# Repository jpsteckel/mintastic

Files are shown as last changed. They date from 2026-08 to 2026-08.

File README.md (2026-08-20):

# Minstastic: Altoids Tin Meshtastic Node
**Mintastic is a low-cost LoRa meshtastic node built as an**
[**Altoids tin gadget**](https://www.instructables.com/10-Projects-for-Altoids-Tins "Other examples")**.**

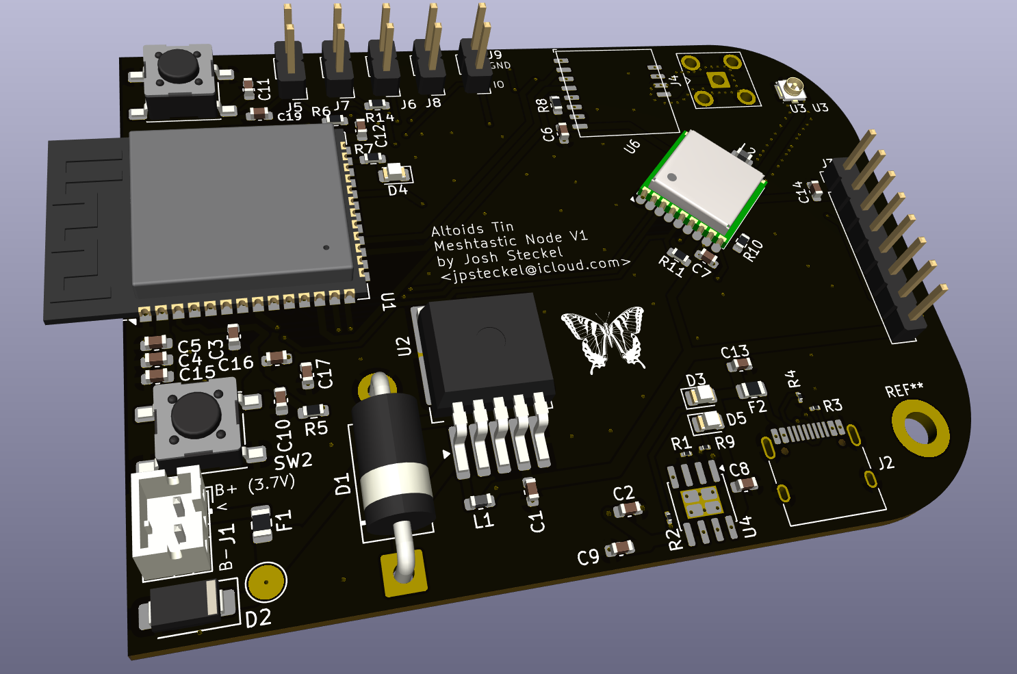
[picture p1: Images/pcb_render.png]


## Abstract
**Note: this project is still a work in progress. I plan on updating and finishing this project by early September.**

This project presents the design and implementation of a compact, low-cost Meshtastic mesh networking node packaged in an everyday Altoids tin enclosure. Motivated by the need for a fully standalone node on a campus mesh network, the device integrates a custom PCB featuring an ESP32 microcontroller, SX1262 LoRa transceiver operating at 915 MHz, GPS module, navigation buttons, and LCD display for a custom user interface. Power is supplied by a 3.7 V 1500 mAh LiPo battery with on-board charging circuitry, while an external whip antenna supports long-range communication. <!-- The completed node achieves approximately 6 miles of unobstructed range (mountain-to-mountain) with an average current draw of 0.150 mA. --> The design demonstrates practical RF system integration, efficient power management, and mechanical packaging constraints, resulting in a portable, inexpensive, and self-contained mesh node suitable for campus and outdoor applications.

## 1. Requirements
|  | Requirement |
|---|---|
| Power | 3.7V 1500mAh LiPo battery with JST connector, approx 1x2 inches. |
| Size | <58mm width. I've gone with 55x75mm to leave room for battery. |
| Bluetooth | Connects via bluetooth to mobile phone with Meshtastic app |
| GPS | Built-in GPS capability for off-grid use |
| Cost | As cheap as possible for me to prototype, <$50/unit "build it yourself" cost |
| Personal Learning Goals | Learn RF and digital PCB design, and build first highly documented project. |

**Preferred Qualities:**
|  | Goal |
|---|---|
| Standalone | Usable without external bluetooth device through built-in user interface |
| Range | ~ 6 mile unobscured |
| Battery Life | >10 hours / <150mA average consumption |

## 2. Design
### Power
The first design concern is being able to both power the board using the LiPo battery, and recharge it. Luckily, most all ESP32, LoRa, and GPS chips support 3.3V VCC, so I only need one regulator chip. I've decided on the **LM2575S-3.3** switching regulator for its efficiency and availability.

For charging and off-board power, I've chosen the **TP4056**, a common charging chip which is powered by 5V via USB-C and outputs 3.7V. This will connect to VBAT which connects to the battery as well as VIN on the regulator.

The circuits surrounding these respective components have been copied mostly from their datasheets.

### MCU
Mintastic will use an ESP32 due to their native bluetooth features. Most could handle this job, I have chosen the **ESP32 S3 N16R8**. Although it costs slightly more than other modules, its large flash memory gives me a lot of room to add features in the future without needing to upgrade hardware.

**Full MCU Pinout**
| ESP32 Pin | Connection | Pulled high/low/NA |
| - | - | - |
| EN | Reset Button | High |
| IO0 | Boot Button | High |
| IO1 | Battery Divider | |
| IO2 | User Button | High |
| IO3 | User Button | High |
| IO4 | GPS Reset | High |
| IO5 | GPS On/Off | High |
| IO6 | User Button | High |
| IO7 | User Button | High |
| IO8 | LoRa SCK | |
| IO9 | LoRa MISO | |
| IO10 | LoRa MOSI | |
| IO11 | LCD Reset | |
| IO12 | LCD SDA | |
| IO13 | LCD SCL | |
| IO14 | LCD CS | |
| IO15 | LCD DC | |
| IO16 | User Button | High |
| IO17 | GPS Tx | |
| IO18 | GPS Rx | |
| USB+ | USB D+ | |
| USB- | USB D- | |
| IO38 | LoRa RF Switch | |
| IO39 | LoRa DIO1 | |
| IO40 | LoRa Busy | |
| IO41 | LoRa NSS | |
| IO42 | LoRa Reset | |
| IO46 | | unconnected/low |
| IO48 | Red LED | |

Note: The periferal connections were decided (mostly) arbitrarily or based on firmware defaults.

All other pins are unconnected.

### Periferals
#### I. LoRa Module
The Semtech SX1262 is the LoRa IC used almost universally for Mesh nodes. For simplicity, I will use the [**Wio-SX1262**](https://wiki.seeedstudio.com/wio_sx1262/) module by Seeed Studio. This compact module features an onboard filter, switch, and IPEX connector, making it ideal for this. (I will be using a separate SMA connector rather than the IPEX for LoRa.)

#### II. GPS Module
I do not want to be reliant on a mobile phone's internet connection for location information, so I plan to use an on-board GPS chip. I've selected the cheap chinese [**ATGM336H**](https://www.alldatasheet.com/html-pdf/2250270/ZHONGKE/ATGM336H/2443/7/ATGM336H.html) module to support GPS for this module.

#### III. 2.4 Inch TFT LCD Display
I've selected a generic ST7789 display for this with a built-in controller. I will simply connect it through a 1x8 pin socket.

### PCB
To fit design constraints, I've set the width of the PCB to be just under the inner lip diameter of the Altoids tin, 55mm, and its height to be ~ 40 mm less than the length of the tin, 75mm, to leave room for the battery. I've also rounded 2 of the board's edges to match the curvature of the tin.

To lower costs, I've decided to use a 2-layer board over a simpler 4-layer design. For this reason, I will need to separate UHF from digital signals so that they can have a solid ground plane beneath each trace.

The dielectric between the layers is far too thick for impedance controlled microstrip traces, so I will use the GCPW (Grounded Coplanar Waveguide) technique.

**Impedance control**

To calculate impedance values, I am using an [online calculator](https://impedancecalculator.com/). 
UHF signal traces will need to be impedance controlled to 50 Ohms. Using GCPW, this requires a 1 mm trace and 0.2 mm gap. This gets us down to 55.7 Ohms, resulting in 0.556 dB/inch loss at 900 MHz. Close enough for this ~0.1 inch line.

I've determined the microstrip traces to have a reasonable impedance for digital signals.

### UI Design

## 3. Manufacturing
Prototype fabricated through JLCPCB. All components were ordered through AliExpress. I assembled the PCB myself using SMT tools at UD.

**Prototype cost breakdown:**
| Item | Cost ($) | Note |
| ---- | ---- | ---- |
| PCB | 4.95 | 24.75/5, includes shipping |
| [Capacitors](https://www.aliexpress.com/item/3256810330121955.html?spm=a2g0o.order_list.order_list_main.10.21ef1802iwNV2p) | 0.20 | 3.19/320 * 20 |
| [Resistors](https://www.aliexpress.com/item/3256810577510361.html?spm=a2g0o.order_list.order_list_main.32.21ef1802iwNV2p) | 0.07 | 2.37/660 * 19 |
| [Inductors](https://www.aliexpress.com/item/3256808828460642.html?spm=a2g0o.order_list.order_list_main.78.21ef1802iwNV2p) | 0.03 | 4.35/300 * 0.029 |
| [LEDs](https://www.aliexpress.com/item/2251800651687366.html?spm=a2g0o.order_list.order_list_main.114.21ef1802iwNV2p) | 0.05 | 1.51/100 * 3 |
| [Resettable Fuses](https://www.aliexpress.com/item/3256805049615392.html?spm=a2g0o.order_list.order_list_main.44.21ef1802iwNV2p) | 0.33 | 3.32/20 * 2 |
| [SS14 Diode](https://www.aliexpress.com/item/3256806391314857.html?spm=a2g0o.order_list.order_list_main.26.21ef1802iwNV2p) | 0.03 | 1.47/50 |
| [IN5819 Diode](https://www.aliexpress.com/item/3256801365779334.html?spm=a2g0o.order_list.order_list_main.425.21ef1802iwNV2p) | 0.02 | 0.91/50
| [USB-C Connector](https://www.aliexpress.com/item/3256804454151365.html?spm=a2g0o.order_list.order_list_main.435.21ef1802iwNV2p) | 0.22 | 2.19/10 |
| [Battery JST connector](https://www.aliexpress.com/item/3256807568732637.html?spm=a2g0o.order_list.order_list_main.102.21ef1802iwNV2p) | 0.09 | 1.77/20 |
| [LiPo Battery](https://www.aliexpress.com/item/3256808031709894.html?spm=a2g0o.order_list.order_list_main.84.21ef1802iwNV2p) | 6.73 | |
| [TP4056](https://www.aliexpress.com/item/2251832528051428.html?spm=a2g0o.order_list.order_list_main.96.21ef1802iwNV2p) | 0.10 | 0.94/10 |
| [LM2575S-3.3](https://www.aliexpress.com/item/3256806770889152.html?spm=a2g0o.order_list.order_list_main.50.21ef1802iwNV2p) | 0.28 | 5.54/20 |
| [ESP32-S3-N16R8](https://www.aliexpress.com/item/3256806005505510.html?spm=a2g0o.order_list.order_list_main.90.21ef1802iwNV2p) | 4.79 | |
| [WIO-SX1262](https://www.aliexpress.com/item/3256808235584580.html?spm=a2g0o.order_list.order_list_main.451.21ef1802iwNV2p) | 4.97 | |
| [ATGM336H](https://www.aliexpress.com/item/3256804828510067.html?spm=a2g0o.order_list.order_list_main.66.21ef1802iwNV2p) | 3.04 | |
| [IPEX connector](https://www.aliexpress.com/item/3256801185019750.html?spm=a2g0o.order_list.order_list_main.108.21ef1802iwNV2p) | 0.15 | 1.50/10 |
| [SMA connector](https://www.aliexpress.com/item/3256807238600626.html?spm=a2g0o.order_list.order_list_main.475.21ef1802iwNV2p) | 0.77 | 3.86/5  |
| [SMA Cable](https://www.aliexpress.com/item/3256803838912502.html?spm=a2g0o.order_list.order_list_main.38.21ef1802iwNV2p) | 2.34 | |
| [2.4in TFT LCD Display](https://www.aliexpress.com/item/3256811879116899.html?spm=a2g0o.order_list.order_list_main.125.21ef1802iwNV2p) | 5.57 | |
| [8-pin socket](https://www.aliexpress.com/item/3256804056304729.html?spm=a2g0o.order_list.order_list_main.72.21ef1802iwNV2p) | 0.19 | 1.94/10 |
| [2-pin headers](https://www.aliexpress.com/item/3256807300285852.html?spm=a2g0o.order_list.order_list_main.140.21ef1802iwNV2p) | 0.05 | 1.63/180 * 5 |
| [Push Buttons](https://www.aliexpress.com/item/3256808033339761.html?spm=a2g0o.order_list.order_list_main.510.21ef1802iwNV2p) | 0.05 | 0.99/100 * 5 |
| [UHF Whip Antenna](https://www.aliexpress.us/item/3256804421300249.html) | 4.60 | |
| [GPS Antenna](https://www.aliexpress.com/item/2251832500323977.html?spm=a2g0o.order_list.order_list_main.20.21ef1802iwNV2p) | 1.59 | |
| Altoids tin | 0.00 | Everyone has one somewhere
| Total | 41.20 | |

Note on above calculations: This is a rough estimate of how much each unit costs at a small scale to self-assemble. Many components, such as resistors, I had to buy in kits. In these cases, I took the cost of the kit, divided it by the total number of pieces included, and multiplied by the number of that component per unit. $40 is about the lowest you will find a mesh node for on Amazon, so this is a reasonable cost. It goes without saying that I would use PCBA for production at scale, but for this project it would have cost ~$193.

## 4. Measurement Setup
...

## 5. Results
| Spec | Target | Simulated | Measured |
| ---- | --- | --- | --- |
|
[Plots]

## 6. Discussion & Lessons Learned
...

## 7. Conclusion
...

## References
I was inspired by Martin Held's [Altoids tin CW radio](https://www.youtube.com/watch?v=zBLEqTVUgEY&list=WL&index=7&pp=iAQBsAgC) project.

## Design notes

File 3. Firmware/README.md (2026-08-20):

# ESP32-S3-N18R8 Metastatic Node — boilerplate

FreeRTOS-based skeleton for a mesh node built around the ESP32-S3 (8MB PSRAM)
and an ST7789V TFT LCD. Right now it only brings up the display so you can
design the UI; other subsystems are scaffolded as stub tasks so they drop
in later without restructuring anything.

## Structure

```
platformio.ini            Build config, board, libs
include/
  config.h                Pin mapping + task stack/priority/core sizing
  shared_state.h           Mutex-guarded NodeState shared across tasks
src/
  main.cpp                 setup()/loop(): creates shared state, starts tasks
  shared_state.cpp          Global SharedState instance
  ui/
    ui.h / ui.cpp           <-- DESIGN THE DISPLAY LOOK HERE
  tasks/
    display_task.h/.cpp     Owns the SPI panel + render loop, calls ui::render()
    system_task.h/.cpp      Heartbeat: updates uptime, prints serial status
    gps_task.h/.cpp          Stub — not started yet
    input_task.h/.cpp       Stub — not started yet
    mesh_task.h/.cpp        Stub — not started yet (Meshtastic goes here)
```

## Why it's laid out this way

- **One task per subsystem**, each pinned to a core and given a priority in
  `config.h`. Display/system run now; GPS/input/mesh are already sized and
  prioritized but not started (commented out in `main.cpp`).
- **`SharedState`** is the only thing tasks share. It's a mutex-protected
  struct (`NodeState`) with `read()` and `update()` helpers — no task talks
  to another task directly, which keeps things sane once GPS, input, and
  Meshtastic are all producing/consuming data at the same time.
- **`ui.cpp` is intentionally decoupled from `display_task.cpp`.** The task
  owns the SPI bus and the timing loop; `ui::render()` just gets a `tft`
  reference and a read-only `NodeState` snapshot every frame. Redesign the
  look by editing `ui.cpp` only — you shouldn't need to touch the task code.

## Before you build

1. **Wiring** — `include/config.h` has placeholder SPI pins for the ST7789V
   (`TFT_SCLK/MOSI/CS/DC/RST/BL`). Update them to match your actual wiring.
2. **Panel size** — defaults to 240x240; change `TFT_WIDTH`/`TFT_HEIGHT` if
   your module is 240x320 (and adjust `TFT_ROTATION` as needed).
3. **Board** — `platformio.ini` targets `esp32-s3-devkitc-1` with QIO octal
   PSRAM (`qio_opi`) and a 16MB flash partition table. Adjust
   `board_upload.flash_size` / `board_build.partitions` if your module's
   flash size differs from what "N18" maps to on your specific board.

## Build / flash

```
pio run -t upload
pio device monitor
```

You should get a black screen with a green node-name header, a live
uptime/status readout, and a blinking dot in the bottom-right corner
confirming the render loop is alive — that's your canvas to redesign.

## Next steps (already scaffolded, not wired in)

- **GPS**: implement `gps_task.cpp` (e.g. with TinyGPS++ over `Serial1` on
  `GPS_RX_PIN`/`GPS_TX_PIN`), then uncomment `gpsTaskStart()` in `main.cpp`.
- **Input**: implement `input_task.cpp` against `BTN_*_PIN` (or swap in an
  encoder library), then uncomment `inputTaskStart()`.
- **Meshtastic**: implement `mesh_task.cpp` around the Meshtastic firmware
  components/library of choice, then uncomment `meshTaskStart()`. It's
  already given the highest task priority in `config.h` since radio timing
  tends to be the most latency-sensitive thing on the node.

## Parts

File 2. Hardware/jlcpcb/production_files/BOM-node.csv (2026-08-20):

Comment | Designator | Footprint | LCSC | Quantity
100k | R18 | R_0805_2012Metric | C149504 | 1
100nF | C10,C11,C12,C15,C16,C17,C18,C19,C20,C21,C22,C23,C3,C5 | C_0603_1608Metric | C14663 | 14
10k | R10,R11,R12,R14,R15,R16,R17,R5,R6,R8 | R_0603_1608Metric | C29718 | 10
10uF | C13,C14,C4,C6,C7,C8,C9 | C_0603_1608Metric | C19702 | 7
10uH | L2 | L_0603_1608Metric | C1035 | 1
1k | R2,R9 | R_0201_0603Metric | C21190 | 2
2.0k | R1 | R_0201_0603Metric | C22975 | 1
220k | R19 | R_0805_2012Metric | C17556 | 1
22uF | C1,C2 | C_0603_1608Metric | C59461 | 2
330 | R13,R7 | R_0603_1608Metric | C23138 | 2
5.1k | R3,R4 | R_0201_0603Metric | C23186 | 2
68uH | L1 | L_0603_1608Metric | C13415 | 1
ATGM336H-6N-74 | U6 | C5804601_COMM-SMD_18P-L10_1-W9_7-P1_1-TL_L76-LB | C5804601 | 1
Green | D5 | LED_0805_2012Metric | C2297 | 1
IPEX-1 | U3 | C2987682_IPEX-SMD_4P-L2_6-W2_6-LS3_0 | C2987682 | 1
Polyfuse 1A | F1,F2 | Fuse_0805_2012Metric | C269104 | 2
RED | D4 | LED_0805_2012Metric | C84256 | 1
SS14 | D2 | D_SMA | C7420316 | 1
TP4056-42-ESOP8 | U4 | SOIC-8-1EP_3.9x4.9mm_P1.27mm_EP2.41x3.3mm_ThermalVias | C16581 | 1
Yellow | D3 | LED_0805_2012Metric | C2296 | 1
USB_C_Receptacle | J2 | USB_C_Receptacle_HRO_TYPE-C-31-M-12 |  | 1
Conn_01x08_Socket | J3 | PinHeader_1x08_P2.54mm_Vertical |  | 1
Wio-SX1262 | U5 | MODULE12P-1.27-11X11.6MM |  | 1
LM2595S-3.3 | U2 | TO-263-5_TabPin3 |  | 1
ESP32-S3-WROOM-1 | U1 | ESP32-S3-WROOM-1 |  | 1
TestPoint | TP1 | TestPoint_Pad_D2.5mm |  | 1
SW_Push | SW4 | SW_SPST_PTS645Sx43SMTR92 |  | 1
SW_Push | SW2 | SW_SPST_PTS645Sx43SMTR92 |  | 1
SMA 915MHz | J4 | SMA_BAT_Wireless_BWSMA-KWE-Z001 |  | 1
Conn_01x02 | J1 | JST_PH_B2B-PH-K_1x02_P2.00mm_Vertical |  | 1
1N5822 | D1 | D_DO-201AD_P15.24mm_Horizontal |  | 1
Conn_01x02_Pin | J9 | PinHeader_1x02_P2.54mm_Vertical |  | 1
Conn_01x02_Pin | J8 | PinHeader_1x02_P2.54mm_Vertical |  | 1
Conn_01x02_Pin | J7 | PinHeader_1x02_P2.54mm_Vertical |  | 1
Conn_01x02_Pin | J6 | PinHeader_1x02_P2.54mm_Vertical |  | 1
Conn_01x02_Pin | J5 | PinHeader_1x02_P2.54mm_Vertical |  | 1

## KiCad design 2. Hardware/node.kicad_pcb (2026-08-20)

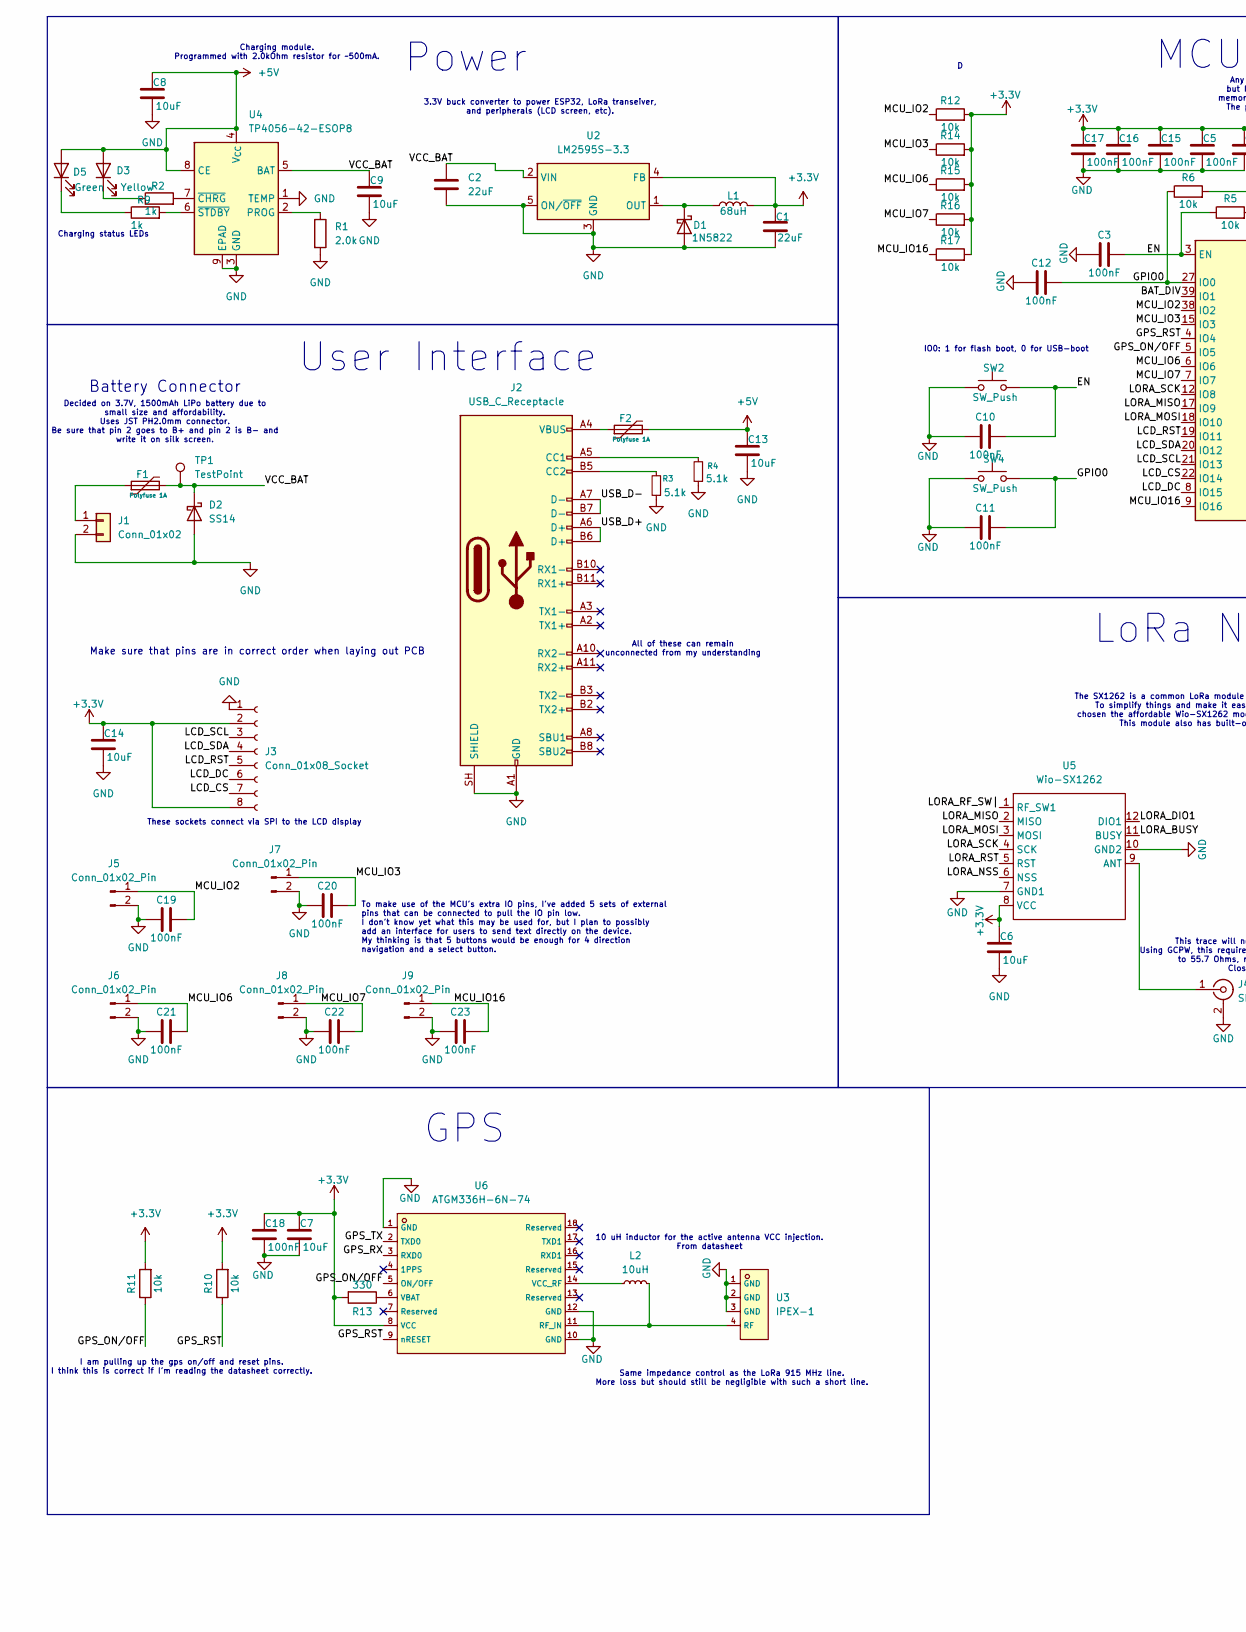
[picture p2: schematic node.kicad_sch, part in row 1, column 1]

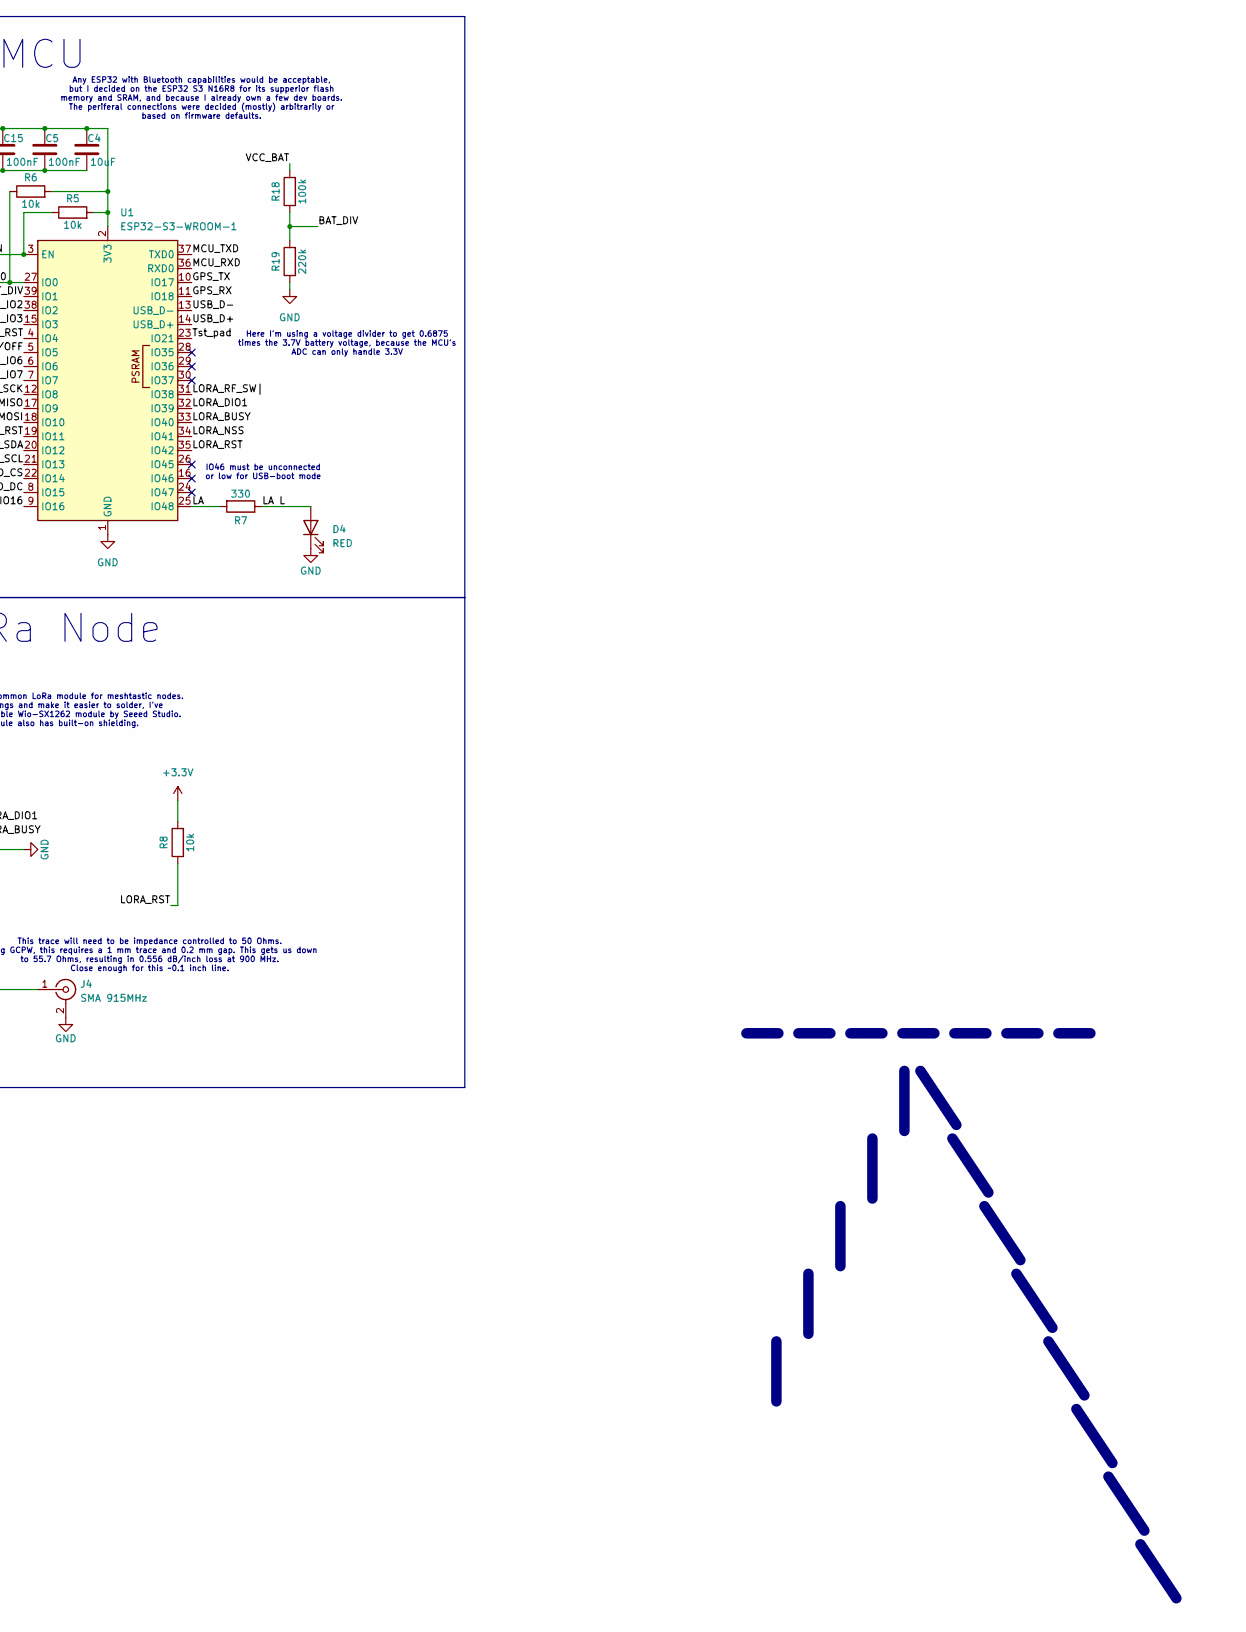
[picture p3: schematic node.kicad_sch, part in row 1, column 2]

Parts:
C1, C2: 22uF; C_0603_1608Metric
C3, C5, C10, C11, C12, C15, C16, C17, C18, C19, C20, C21, C22, C23: 100nF; C_0603_1608Metric
C4, C6, C7, C8, C9, C13, C14: 10uF; C_0603_1608Metric
D1: 1N5822; D_DO-201AD_P15.24mm_Horizontal
D2: SS14; D_SMA
D3: Yellow; LED_0805_2012Metric
D4: RED; LED_0805_2012Metric
D5: Green; LED_0805_2012Metric
F1, F2: Polyfuse 1A; Fuse_0805_2012Metric
J1: Conn_01x02; JST_PH_B2B-PH-K_1x02_P2.00mm_Vertical
J2: USB_C_Receptacle; USB_C_Receptacle_HRO_TYPE-C-31-M-12
J3: Conn_01x08_Socket; PinHeader_1x08_P2.54mm_Vertical
J4: SMA 915MHz; SMA_BAT_Wireless_BWSMA-KWE-Z001
J5, J6, J7, J8, J9: Conn_01x02_Pin; PinHeader_1x02_P2.54mm_Vertical
L1: 68uH; L_0603_1608Metric
L2: 10uH; L_0603_1608Metric
R1: 2.0k; R_0201_0603Metric
R2, R9: 1k; R_0201_0603Metric
R3, R4: 5.1k; R_0201_0603Metric
R5, R6, R8, R10, R11, R12, R14, R15, R16, R17: 10k; R_0603_1608Metric
R7, R13: 330; R_0603_1608Metric
R18: 100k; R_0805_2012Metric
R19: 220k; R_0805_2012Metric
SW2, SW4: SW_Push; SW_SPST_PTS645Sx43SMTR92
TP1: TestPoint; TestPoint_Pad_D2.5mm
U1: ESP32-S3-WROOM-1
U2: LM2595S-3.3; TO-263-5_TabPin3
U3: IPEX-1; C2987682_IPEX-SMD_4P-L2_6-W2_6-LS3_0; LCSC C2987682
U4: TP4056-42-ESOP8; SOIC-8-1EP_3.9x4.9mm_P1.27mm_EP2.41x3.3mm_ThermalVias
U5: Wio-SX1262; MODULE12P-1.27-11X11.6MM; MPN Wio-SX1262
U6: ATGM336H-6N-74; C5804601_COMM-SMD_18P-L10_1-W9_7-P1_1-TL_L76-LB; LCSC C5804601

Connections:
+3.3V: C1.1, C4.1, C5.1, C6.1, C7.1, C14.1, C15.1, C16.1, C17.1, C18.1, J3.2, J3.8, L1.2, R5.2, R6.2, R8.2, R10.2, R11.2, R12.2, R13.2, R14.2, R15.2, R16.2, R17.2, U1.2 (3V3), U2.4 (FB), U5.8 (VCC), U6.8 (VCC)
+5V: C8.1, C13.1, D3.2 (A), D5.2 (A), F2.2, U4.4 (V_{CC}), U4.8 (CE)
/BAT_DIV: R18.1, R19.2, U1.39 (IO1)
/EN: C3.2, C10.2, R5.1, SW2.2, U1.3 (EN)
/GPIO0: C11.2, C12.2, R6.1, SW4.2, U1.27 (IO0)
/GPS_ON/OFF: R11.1, U1.5 (IO5), U6.5 (ON/OFF)
/GPS_RST: R10.1, U1.4 (IO4), U6.9 (nRESET)
/GPS_RX: U1.11 (IO18), U6.3 (RXD0)
/GPS_TX: U1.10 (IO17), U6.2 (TXD0)
/LA: R7.2, U1.25 (IO48)
/LA L: D4.2 (A), R7.1
/LCD_CS: J3.7, U1.22 (IO14)
/LCD_DC: J3.6, U1.8 (IO15)
/LCD_RST: J3.5, U1.19 (IO11)
/LCD_SCL: J3.3, U1.21 (IO13)
/LCD_SDA: J3.4, U1.20 (IO12)
/LORA_BUSY: U1.33 (IO40), U5.11 (BUSY)
/LORA_DIO1: U1.32 (IO39), U5.12 (DIO1)
/LORA_MISO: U1.17 (IO9), U5.2 (MISO)
/LORA_MOSI: U1.18 (IO10), U5.3 (MOSI)
/LORA_NSS: U1.34 (IO41), U5.6 (NSS)
/LORA_RF_SW|: U1.31 (IO38), U5.1 (RF_SW1)
/LORA_RST: R8.1, U1.35 (IO42), U5.5 (RST)
/LORA_SCK: U1.12 (IO8), U5.4 (SCK)
/MCU_IO2: C19.2, J5.1, R12.1, U1.38 (IO2)
/MCU_IO3: C20.2, J7.1, R14.1, U1.15 (IO3)
/MCU_IO6: C21.2, J6.1, R15.1, U1.6 (IO6)
/MCU_IO7: C22.2, J8.1, R16.1, U1.7 (IO7)
/MCU_IO16: C23.2, J9.1, R17.1, U1.9 (IO16)
/MCU_RXD: U1.36 (RXD0)
/MCU_TXD: U1.37 (TXD0)
/Tst_pad: U1.23 (IO21)
/USB_D+: J2.A6 (D+), J2.B6 (D+), U1.14 (USB_D+)
/USB_D-: J2.A7 (D-), J2.B7 (D-), U1.13 (USB_D-)
/VCC_BAT: C2.1, C9.1, D2.1 (K), F1.2, R18.2, TP1.1 (1_1), U2.2 (VIN), U4.5 (BAT)
GND: C1.2, C2.2, C3.1, C4.2, C5.2, C6.2, C7.2, C8.2, C9.2, C10.1, C11.1, C12.1, C13.2, C14.2, C15.2, C16.2, C17.2, C18.2, C19.1, C20.1, C21.1, C22.1, C23.1, D1.2 (A), D2.2 (A), D4.1 (K), J1.2, J2.A1 (GND), J2.A12 (GND), J2.B1 (GND), J2.B12 (GND), J2.SH (SHIELD), J3.1, J4.2 (Ext), J5.2, J6.2, J7.2, J8.2, J9.2, R1.2, R3.1, R4.1, R19.1, SW2.1, SW4.1, U1.1 (GND), U1.40 (GND), U1.41 (GND), U2.3 (GND), U2.5 (ON/~OFF), U3.1 (GND), U3.2 (GND), U3.3 (GND), U4.1 (TEMP), U4.3 (GND), U4.9 (EPAD), U5.7 (GND1), U5.10 (GND2), U6.1 (GND), U6.10 (GND), U6.12 (GND)
unnamed: D1.1 (K), L1.1, U2.1 (OUT)
unnamed: D3.1 (K), R2.1
unnamed: D5.1 (K), R9.1
unnamed: F2.1, J2.A4 (VBUS), J2.A9 (VBUS), J2.B4 (VBUS), J2.B9 (VBUS)
unnamed: F1.1, J1.1
unnamed: J2.A5 (CC1), R4.2
unnamed: J2.B5 (CC2), R3.2
unnamed: J4.1 (In), U5.9 (ANT)
unnamed: L2.2, U3.4 (RF), U6.11 (RF_IN)
unnamed: R1.1, U4.2 (PROG)
unnamed: R2.2, U4.7 (~CHRG)
unnamed: R9.2, U4.6 (~STDBY)
unnamed: R13.1, U6.6 (VBAT)
unnamed: L2.1, U6.14 (VCC_RF)

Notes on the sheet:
User Interface
Here I'm using a voltage divider to get 0.6875 times the 3.7V battery voltage, because the MCU's ADC can only handle 3.3V
Power
The SX1262 is a common LoRa module for meshtastic nodes. To simplify things and make it easier to solder, I've chosen the affordable Wio-SX1262 module by Seeed Studio. This module also has built-on shielding.
These sockets connect via SPI to the LCD display
Make sure that pins are in correct order when laying out PCB
IO46 must be unconnected or low for USB-boot mode
GPS
MCU
3.3V buck converter to power ESP32, LoRa transeiver, and peripherals (LCD screen, etc).
LoRa Node
Same impedance control as the LoRa 915 MHz line. More loss but should still be negligible with such a short line.
Battery Connector
------- |\ | \ | \ | \ | \ \ \ \
All of these can remain unconnected from my understanding
This trace will need to be impedance controlled to 50 Ohms. Using GCPW, this requires a 1 mm trace and 0.2 mm gap. This gets us down to 55.7 Ohms, resulting in 0.556 dB/inch loss at 900 MHz. Close enough for this ~0.1 inch line.
I am pulling up the gps on/off and reset pins. I think this is correct if I'm reading the datasheet correctly.
Charging module. Programmed with 2.0kOhm resistor for ~500mA.
To make use of the MCU's extra IO pins, I've added 5 sets of external pins that can be connected to pull the IO pin low. I don't know yet what this may be used for, but I plan to possibly add an interface for users to send text directly on the device. My thinking is that 5 buttons would be enough f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
Any ESP32 with Bluetooth capabilities would be acceptable, but I decided on the ESP32 S3 N16R8 for its supperior flash memory and SRAM, and because I already own a few dev boards. The periferal connections were decided (mostly) arbitrarily or based on firmware defaults.
Charging status LEDs
Decided on 3.7V, 1500mAh LiPo battery due to small size and affordability. Uses JST PH2.0mm connector. Be sure that pin 2 goes to B+ and pin 2 is B- and write it on silk screen.
IO0: 1 for flash boot, 0 for USB-boot
10 uH inductor for the active antenna VCC injection. From datasheet

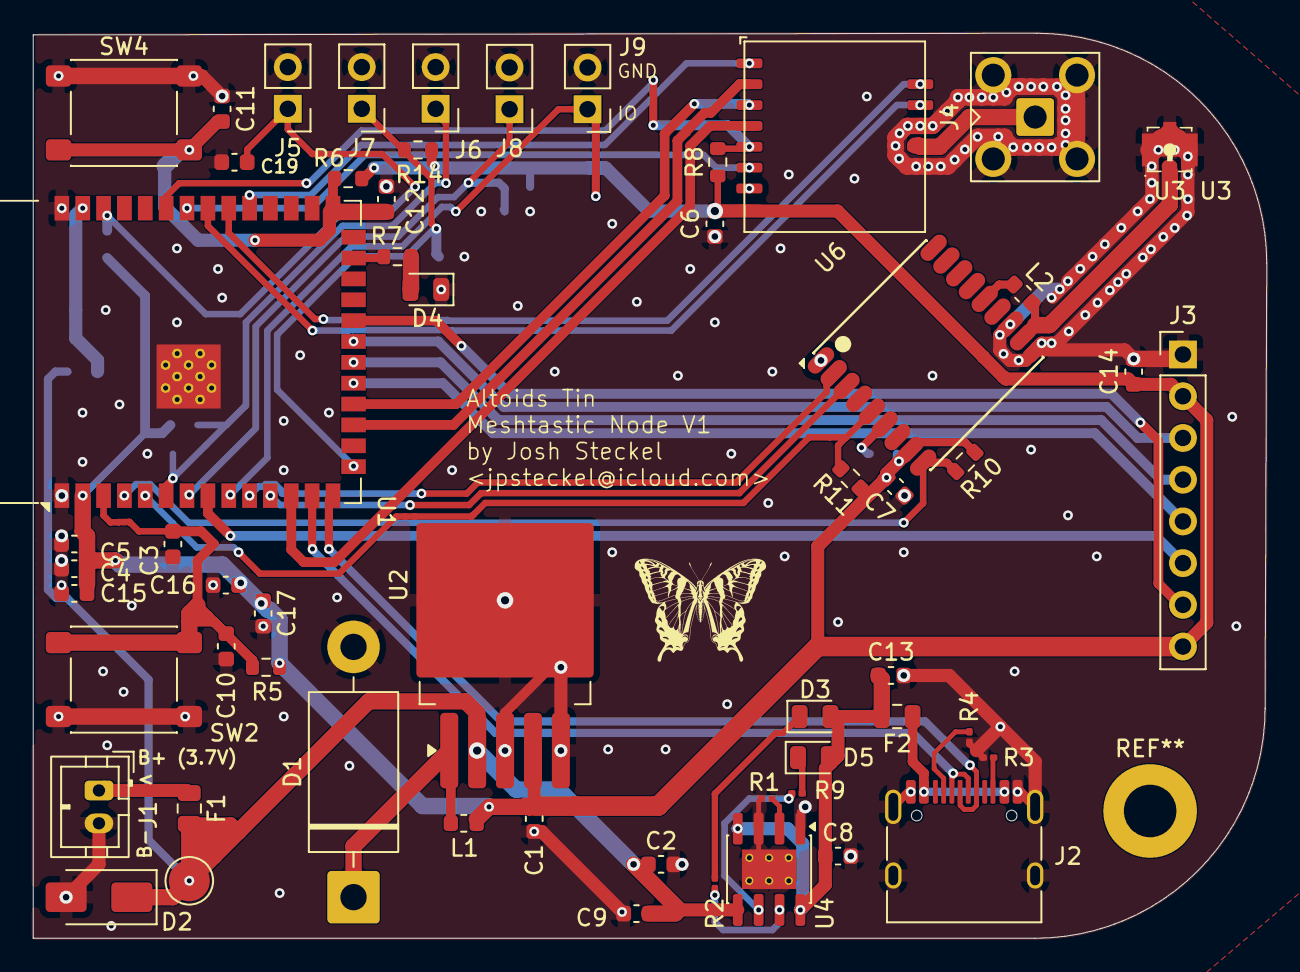
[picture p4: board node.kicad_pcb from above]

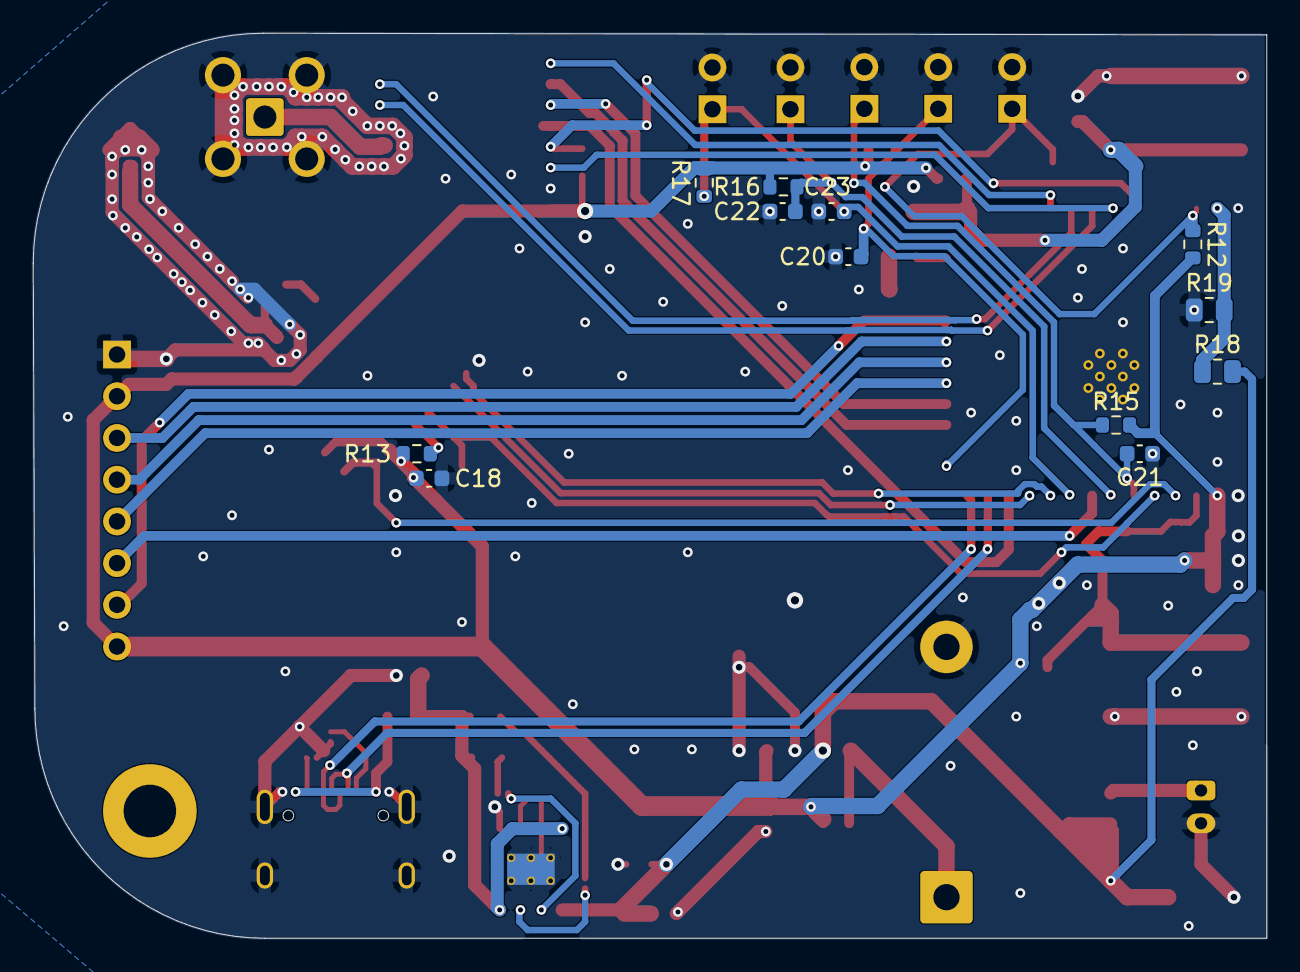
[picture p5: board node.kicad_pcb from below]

Board: 2 copper layers, 75.1 x 55.1 mm, 69 parts (12 on the bottom side), 47 nets.

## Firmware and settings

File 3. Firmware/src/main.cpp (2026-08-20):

#include <Arduino.h>

#include "config.h"
#include "shared_state.h"
#include "tasks/display_task.h"
#include "tasks/system_task.h"

// Not started yet — implement + uncomment when ready:
// #include "tasks/gps_task.h"
// #include "tasks/input_task.h"
// #include "tasks/mesh_task.h"

void setup() {
    Serial.begin(9600);
    delay(200);  // let USB CDC settle
    Serial.printf("\n%s booting...\n", NODE_NAME);

    sharedState.begin();

    displayTaskStart();
    systemTaskStart();

    // gpsTaskStart();
    // inputTaskStart();
    // meshTaskStart();

    Serial.println("setup() done — tasks running under FreeRTOS.");
}

void loop() {
    // Intentionally empty: all work happens in FreeRTOS tasks.
    // Arduino's loop() itself runs as a low-priority task on core 1;
    // we just idle it here.
    vTaskDelay(pdMS_TO_TICKS(1000));
}

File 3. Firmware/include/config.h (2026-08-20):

#pragma once

// =============================================================================
// config.h — central place for pin mapping, task sizing, and node identity.
// Edit the DISPLAY PINS section to match your actual wiring.
// =============================================================================

// ---------------------------------------------------------------------------
// Node identity (placeholder — will matter once Meshtastic is integrated)
// ---------------------------------------------------------------------------
#define NODE_NAME "META-NODE-01"

// ---------------------------------------------------------------------------
// Display: ST7789V TFT, driven over SPI
// ---------------------------------------------------------------------------
// Adjust these to match your wiring. Values below are a common default for
// ESP32-S3 dev boards with the display on the "default" VSPI-ish pins.
#define TFT_SCLK   13
#define TFT_MOSI   12
#define TFT_MISO   -1      // not used by most ST7789 modules
#define TFT_CS     14
#define TFT_DC      15
#define TFT_RST     11
#define TFT_BL      -1      // backlight, set -1 if tied directly to 3V3

// Panel geometry — common ST7789V modules are 240x240 or 240x320.
#define TFT_WIDTH   240
#define TFT_HEIGHT  320
#define TFT_ROTATION 0

// SPI clock for the panel
#define TFT_SPI_HZ  40000000UL

// ---------------------------------------------------------------------------
// Future peripherals (not wired up yet — placeholders for pin planning)
// ---------------------------------------------------------------------------
// GPS (e.g. UART NMEA module)
#define GPS_RX_PIN      17
#define GPS_TX_PIN      18
#define GPS_BAUD        9600

// User input (buttons / rotary encoder — adjust to your hardware)
#define BTN_UP_PIN      4
#define BTN_DOWN_PIN    5
#define BTN_SELECT_PIN  6

// ---------------------------------------------------------------------------
// FreeRTOS task sizing
// ---------------------------------------------------------------------------
// ESP32-S3 is dual-core (PRO_CPU = 0, APP_CPU = 1). Arduino's loop() and
// WiFi/BT stack normally run on core 1, so we pin the display task there too
// (it's not timing critical relative to core 0) and leave core 0 free for
// future radio/mesh work, which tends to be latency sensitive.
#define DISPLAY_TASK_STACK      (4 * 1024)
#define DISPLAY_TASK_PRIORITY   2
#define DISPLAY_TASK_CORE       1

#define SYSTEM_TASK_STACK       (2 * 1024)
#define SYSTEM_TASK_PRIORITY    1
#define SYSTEM_TASK_CORE        1

// Reserved for when GPS/input/mesh tasks are wired in:
#define GPS_TASK_STACK          (3 * 1024)
#define GPS_TASK_PRIORITY       3
#define GPS_TASK_CORE           0

#define INPUT_TASK_STACK        (2 * 1024)
#define INPUT_TASK_PRIORITY     3
#define INPUT_TASK_CORE         1

#define MESH_TASK_STACK         (8 * 1024)
#define MESH_TASK_PRIORITY      4
#define MESH_TASK_CORE          0

// Target UI frame interval (ms). 33ms ≈ 30fps — plenty for a status UI.
#define DISPLAY_FRAME_INTERVAL_MS  33
